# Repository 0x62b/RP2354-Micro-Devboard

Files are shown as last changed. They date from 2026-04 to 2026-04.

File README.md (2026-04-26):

# RP2354-Micro-Devboard
A devboard based on the RP2354 in a small form factor. It is roughly the size of a Seeed Xiao RP2350, and it was going to be pin compatible, before I realised what a messy routing job that was going to be, so I switched the layout for something more logical.

This is probably just going to be used for some small boards that need an RP2350 but that I don't want to directly build the MCU into, without having to go acquire a Xiao, supermini, or something like that.

*many of the files are named as RP2350 because that is what I was using before

The board is compatible with any firmware written for the Pi Pico/RP2350, as long as they don't use the omitted GPIO pins anyway...

Note! The BOM.csv in project root is the LCSC exported BOM with links, while the BOM list in `production/` is the original 
KiCad exported BOM

# Features
* Based on RP2354A with 2MB onboard flash (small flash is a compromise for small size)
* 2 layer PCB (this killed my sanity)
* 10 GPIO outputs
* USB Micro B power/data connection
* a really REALLY messy PCB routing job (it passed DRC tho so I guess thats something...)

Zine page (yes the render is outdated)\
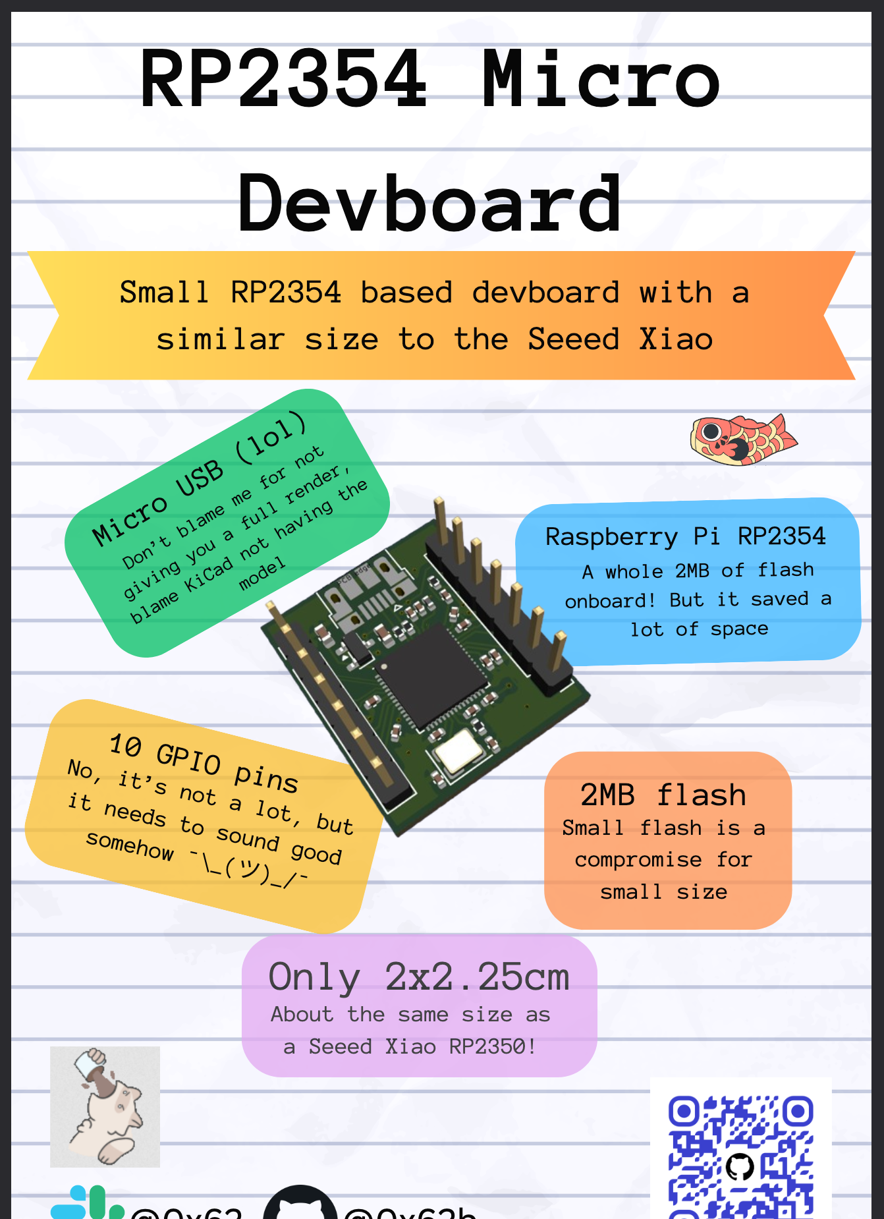
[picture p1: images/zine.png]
zine page


Finished schematic (I'm using the 2350A footprint because they're pin compatible)\
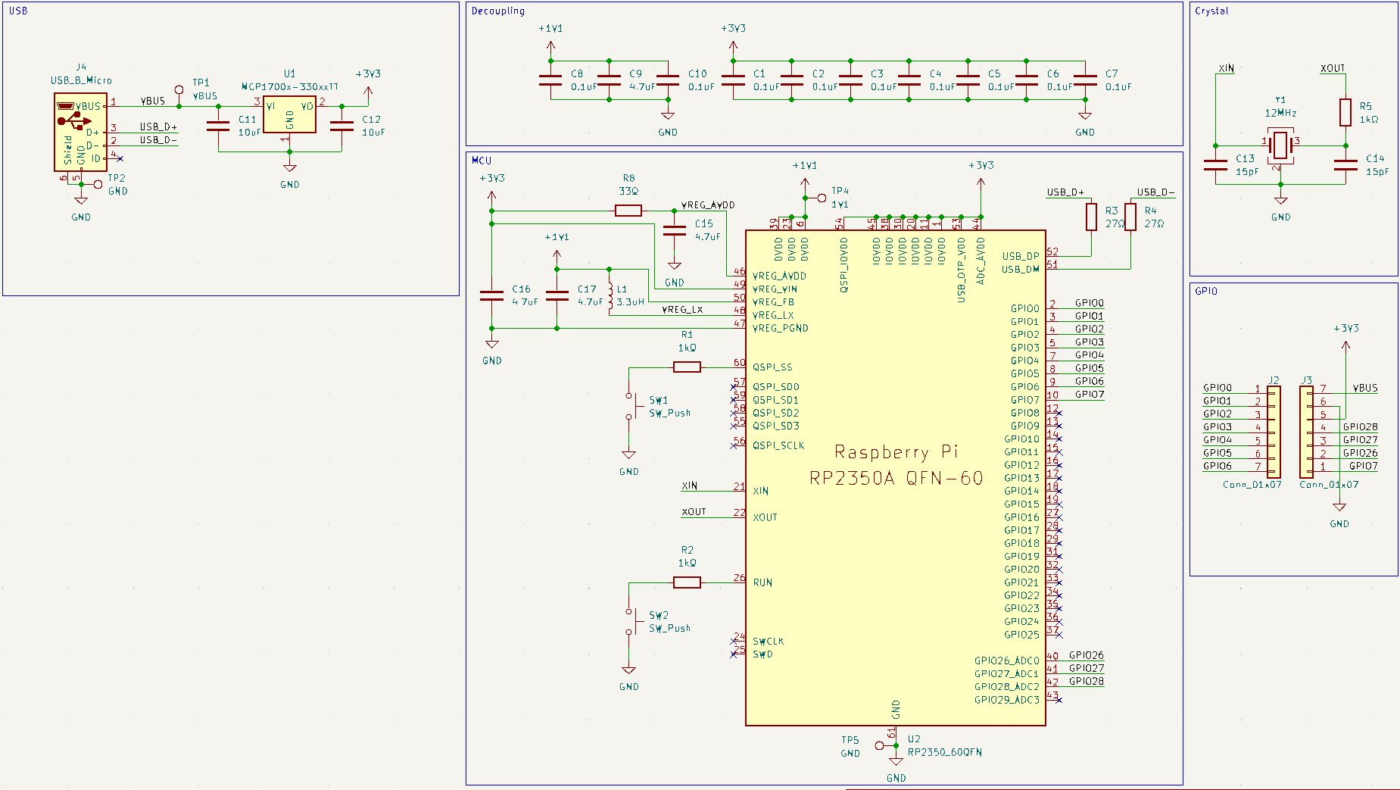
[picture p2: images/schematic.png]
Finished schematic


Finished PCB\
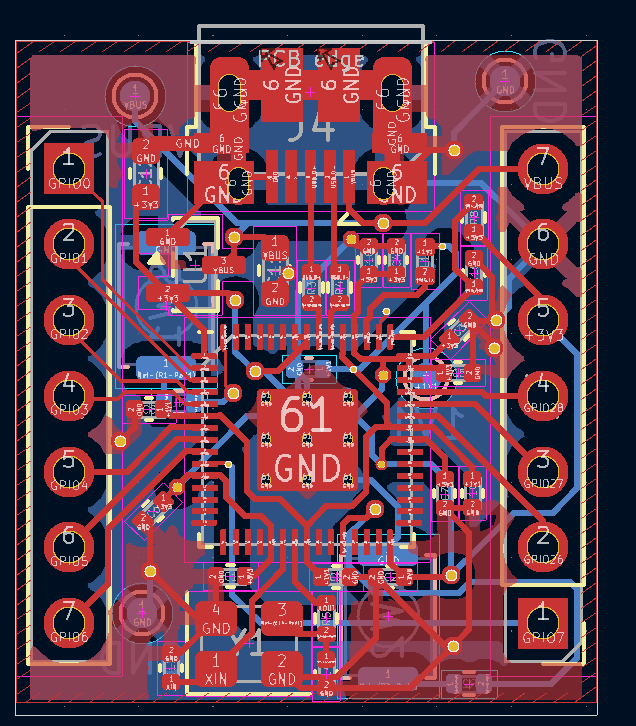
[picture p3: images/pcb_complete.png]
Finished PCB


PCB render\
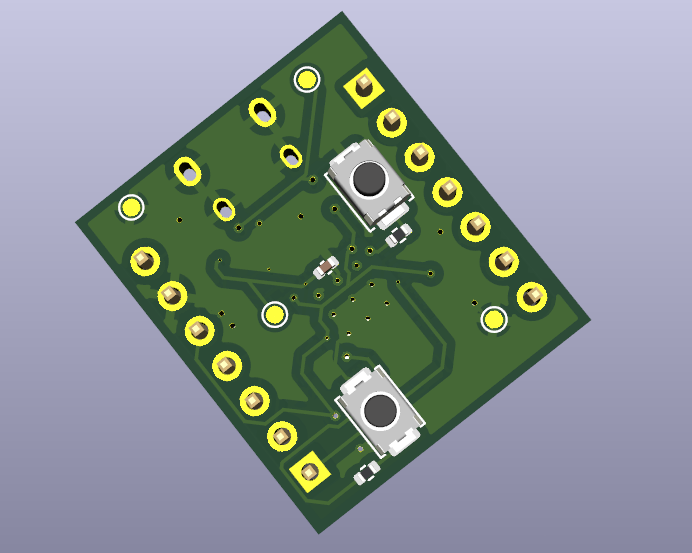
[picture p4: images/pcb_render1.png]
PCB render 1

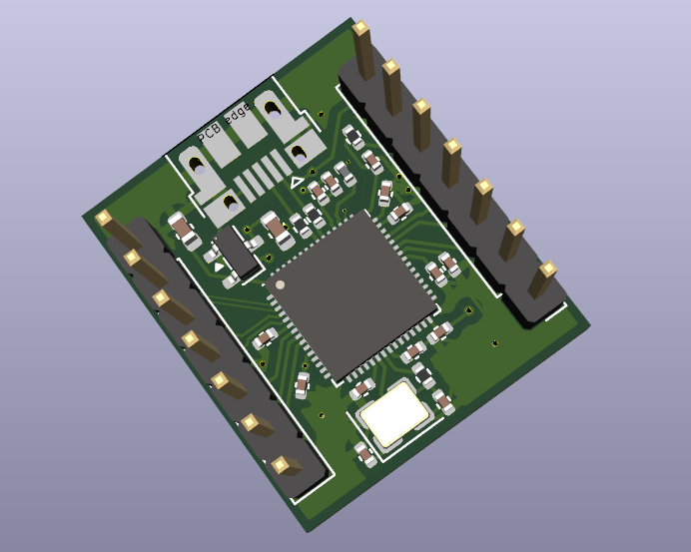
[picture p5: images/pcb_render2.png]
PCB render 2


JLCPCB order\
Extra cost comes from lead-free HASL
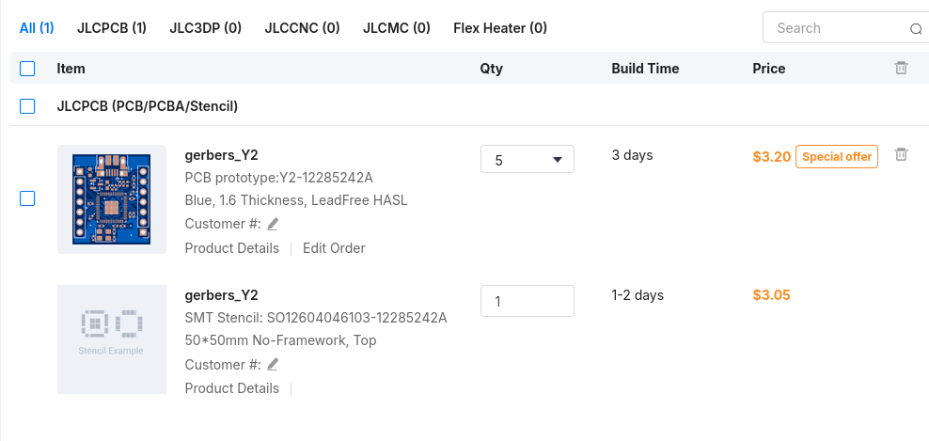
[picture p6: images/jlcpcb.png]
JLCPCB order


LCSC order\
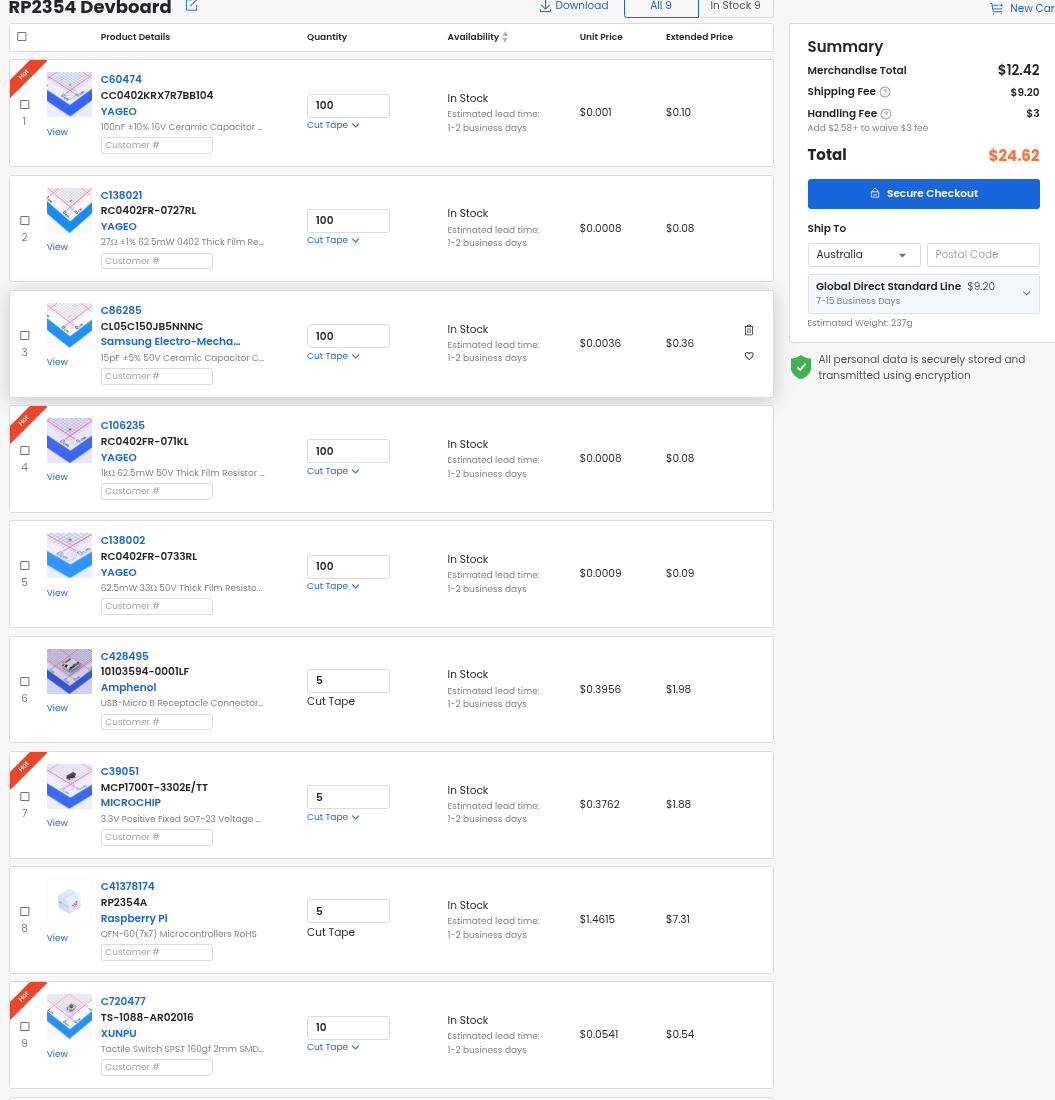
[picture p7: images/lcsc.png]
LCSC order


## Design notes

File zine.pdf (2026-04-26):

## Small RP2354 based devboard with a similar size to the Seeed Xiao

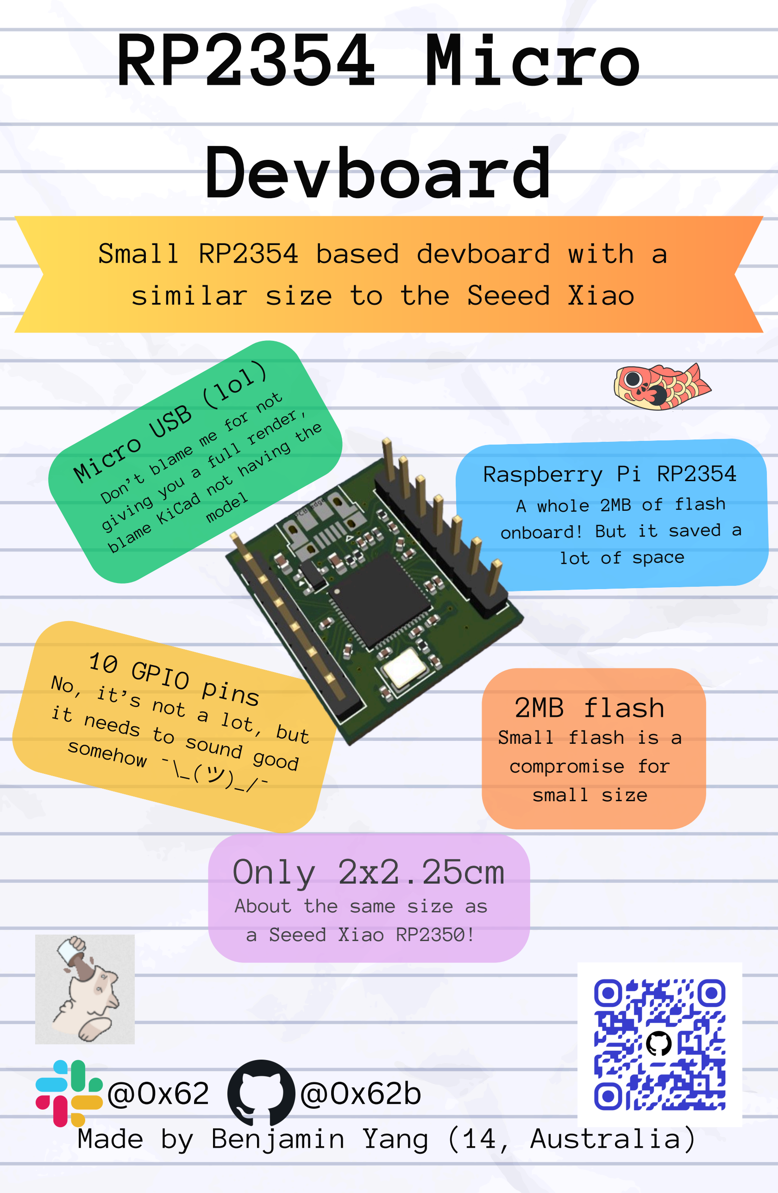
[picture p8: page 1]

# @0x62 @0x62b

## Micro USB (lol)

Don’t blame me for not
giving you a full render,
blame KiCad not having the

model

## 2MB flash

Small flash is a
compromise for
small size

## 10 GPIO pins

### No, it’s not a lot, but it needs to sound good somehow ¯\_(ツ)_/¯

## Raspberry Pi RP2354

A whole 2MB of flash
onboard! But it saved a
lot of space

# Only 2x2.25cm

About the same size as
a Seeed Xiao RP2350!

# RP2354 Micro Devboard

## Made by Benjamin Yang (14, Australia)

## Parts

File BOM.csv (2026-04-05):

RP2350-Micro-Devboard.csv |  |  |  |  |  |  |  |  |  | LCSC BOM Quotation
 |  |  |  |  |  |  |  |  |  | BOM Date Created：05/04/26 15:54:44 |  |  |  | BOM Export Date: 05/04/26 17:32:11 |  |  |  | The matching result is a real-time query result, availability and prices may fluctuate. Backorder items are estimated prices for your reference, please submit "Create Quote" to get the real price. All information is provided "as is" and is subject to change without notice. Any use made of the information provided is without recourse to LCSC and at the user's risk.
 |  |  |  |  |  |  |  |  |  | EST TOTAL :$6.57 |  |  |  | Website：https://www.lcsc.com/bom
Uploaded data |  |  |  |  |  |  |  |  |  | LCSC Matching Results
LCSC# | Mfr. | Mrf# | Description | Package | Value | Customer Part Number | Quantity | Target Price(USD) | Target Lead Time(Business Days) | Mrf# | Mfr. | Order Qty. | Unit Price(USD) | Ext.Price(USD) | LCSC# | Package | Min | Mult | SPQ | Availability | Stock Status | Customer Notes | Description | Matched status | Product Link
 |  |  | 0.1uF | C_0402_1005Metric |  | - | 9 |  |  | CC0402KRX7R7BB104 | YAGEO | 100 | 0.0010 | 0.10 | C60474 | 0402 | 100 | 100 | 10000 | 12680400 | In Stock |  | 100nF ±10% 16V Ceramic Capacitor X7R 0402 | Partial Matches | https://www.lcsc.com/product-detail/C60474.html
 |  |  | 27Ω | R_0402_1005Metric |  | - | 2 |  |  | RC0402FR-0727RL | YAGEO | 100 | 0.0008 | 0.08 | C138021 | 0402 | 100 | 100 | 10000 | 133600 | In Stock |  | 27Ω ±1% 62.5mW 0402 Thick Film Resistor | Partial Matches | https://www.lcsc.com/product-detail/C138021.html
 |  |  | 15pF | C_0402_1005Metric |  | - | 2 |  |  | CL05C150JB5NNNC | Samsung Electro-Mechanics | 100 | 0.0036 | 0.36 | C86285 | 0402 | 100 | 100 | 10000 | 291000 | In Stock |  | 15pF ±5% 50V Ceramic Capacitor C0G 0402 | Partial Matches | https://www.lcsc.com/product-detail/C86285.html
 |  |  | 1kΩ | R_0402_1005Metric |  | - | 3 |  |  | RC0402FR-071KL | YAGEO | 100 | 0.0008 | 0.08 | C106235 | 0402 | 100 | 100 | 10000 | 5019500 | In Stock |  | 1kΩ 62.5mW 50V Thick Film Resistor ±100ppm/℃ ±1% 0402 Chip Resistor - Surface Mount RoHS | Partial Matches | https://www.lcsc.com/product-detail/C106235.html
 |  |  | 33Ω | R_0402_1005Metric |  | - | 1 |  |  | RC0402FR-0733RL | YAGEO | 100 | 0.0009 | 0.09 | C138002 | 0402 | 100 | 100 | 10000 | 258300 | In Stock |  | 62.5mW 33Ω 50V Thick Film Resistor ±100ppm/℃ ±1% 0402 Chip Resistor - Surface Mount RoHS | Partial Matches | https://www.lcsc.com/product-detail/C138002.html
 |  |  | USB_B_Micro | USB_Micro-B_Amphenol_10103594-0001LF_Horizontal_modified |  | - | 1 |  |  | 10103594-0001LF | Amphenol | 5 | 0.3956 | 1.98 | C428495 | SMD | 5 | 5 | 1500 | 26590 | In Stock |  | USB-Micro B Receptacle Connector 5 Position Surface Mount, Right Angle | Partial Matches | https://www.lcsc.com/product-detail/C428495.html
C39051 |  |  | MCP1700x-330xxTT | SOT-23 |  | - | 1 |  |  | MCP1700T-3302E/TT | MICROCHIP | 5 | 0.3762 | 1.88 | C39051 | SOT-23 | 5 | 5 | 3000 | 9525 | In Stock |  | 3.3V Positive Fixed SOT-23 Voltage Regulators - Linear, Low Drop Out (LDO) Regulators RoHS | Exact Matches | https://www.lcsc.com/product-detail/C39051.html
C41378174 |  |  | RP2354_60QFN | RP2354-QFN-60-1EP_7x7_P0.4mm_EP3.4x3.4mm_ThermalVias |  | - | 1 |  |  | RP2354A | Raspberry Pi | 1 | 1.4615 | 1.46 | C41378174 | QFN-60(7x7) | 1 | 1 | 3000 | 156 | In Stock |  | QFN-60(7x7) Microcontrollers RoHS | Exact Matches | https://www.lcsc.com/product-detail/C41378174.html
 |  |  | GND | TestPoint_Pad_D1.0mm |  |  | 2 |  |  | -(The data has been deleted.) | - | - | - | - | - | - | - | - | - | - | - | - | - | -
 |  |  | 1V1 | TestPoint_Pad_D1.0mm |  |  | 1 |  |  | -(The data has been deleted.) | - | - | - | - | - | - | - | - | - | - | - | - | - | -
C720477 |  |  | SW_Push | SW_Push_SPST_NO_Alps_SKRK |  | - | 2 |  |  | TS-1088-AR02016 | XUNPU | 10 | 0.0541 | 0.54 | C720477 | SMD,4x3mm | 10 | 10 | 4000 | 390540 | In Stock |  | Tactile Switch SPST 160gf 2mm SMD (SMT) Tab 4mm x 3mm Surface Mount | Exact Matches | https://www.lcsc.com/product-detail/C720477.html
 |  |  | VBUS | TestPoint_Pad_D1.0mm |  |  | 1 |  |  | -(The data has been deleted.) | - | - | - | - | - | - | - | - | - | - | - | - | - | -

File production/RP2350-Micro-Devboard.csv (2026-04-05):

Id | Designator | Footprint | Quantity | Designation | Supplier and ref
1 | C16,C15,C9,C17 | C_0402_1005Metric | 4 | 4.7uF
2 | J3,J2 | PinHeader_1x07_P2.54mm_Vertical | 2 | Conn_01x07
3 | Y1 | Crystal_SMD_3225-4Pin_3.2x2.5mm | 1 | 12MHz
4 | C12,C11 | C_0603_1608Metric | 2 | 10uF
5 | L1 | L_0402_1005Metric | 1 | 3.3uH
6 | C7,C10,C4,C5,C8,C6,C2,C3,C1 | C_0402_1005Metric | 9 | 0.1uF
7 | R3,R4 | R_0402_1005Metric | 2 | 27Ω
8 | C13,C14 | C_0402_1005Metric | 2 | 15pF
9 | R5,R1,R2 | R_0402_1005Metric | 3 | 1kΩ
10 | R8 | R_0402_1005Metric | 1 | 33Ω
11 | J4 | USB_Micro-B_Amphenol_10103594-0001LF_Horizontal_modified | 1 | USB_B_Micro
12 | U1 | SOT-23 | 1 | MCP1700x-330xxTT
13 | U2 | RP2350-QFN-60-1EP_7x7_P0.4mm_EP3.4x3.4mm_ThermalVias | 1 | RP2350_60QFN
14 | TP2,TP5 | TestPoint_Pad_D1.0mm | 2 | GND
15 | TP4 | TestPoint_Pad_D1.0mm | 1 | 1V1
16 | SW1,SW2 | SW_Push_SPST_NO_Alps_SKRK | 2 | SW_Push
17 | TP1 | TestPoint_Pad_D1.0mm | 1 | VBUS

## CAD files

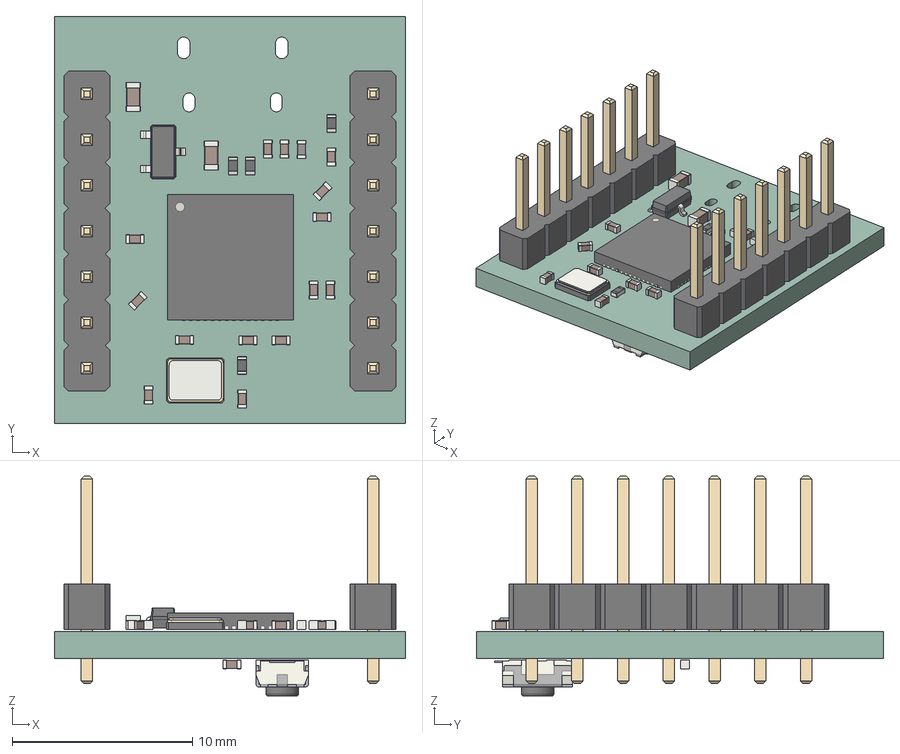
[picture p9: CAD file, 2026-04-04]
cad/RP2350-Micro-Devboard.step
19.5 x 22.6 x 12.2 mm
C_0402_1005Metric x 15
PinHeader_1x07_P2.54mm_Vertical x 2
Crystal_SMD_3225-4Pin_3.2x2.5mm
C_0603_1608Metric x 2
L_0402_1005Metric
R_0402_1005Metric x 4
SOT-23
QFN-56-1EP_7x7mm_P0.4mm_EP5.6x5.6mm
SW_Push_SPST_NO_Alps_SKRK
RP2350-Micro-Devboard_PCB

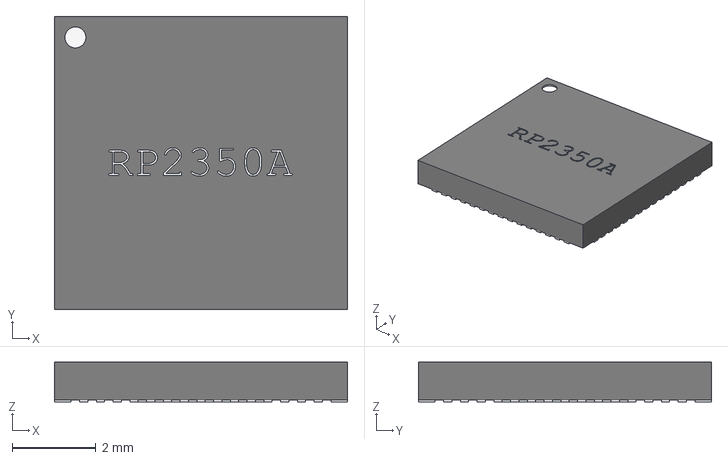
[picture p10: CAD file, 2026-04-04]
pcb/RP2350_QFN60.step
7.00 x 7.00 x 0.95 mm

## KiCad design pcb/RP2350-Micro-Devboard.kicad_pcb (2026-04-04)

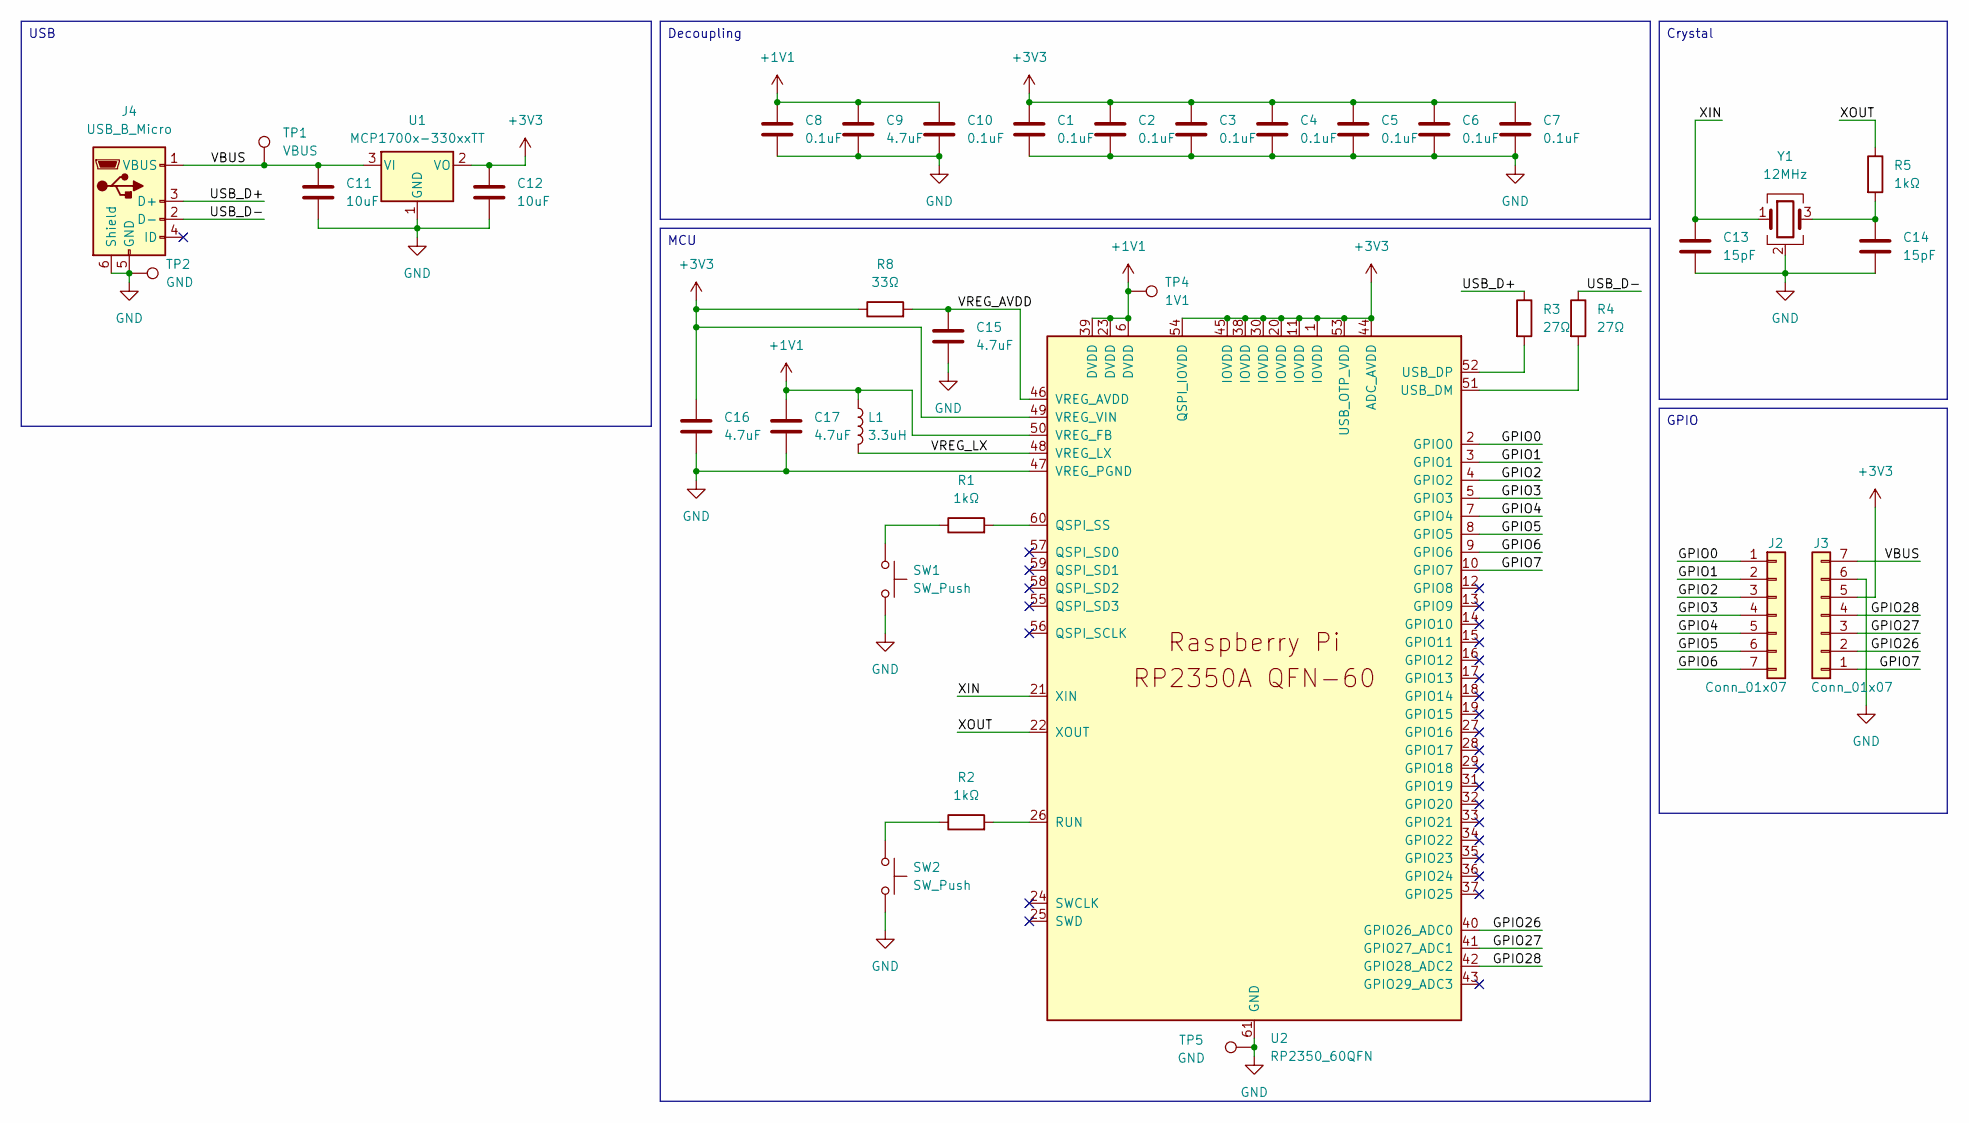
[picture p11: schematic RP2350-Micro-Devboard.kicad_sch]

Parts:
C1, C2, C3, C4, C5, C6, C7, C8, C10: 0.1uF; C_0402_1005Metric
C9, C15, C16, C17: 4.7uF; C_0402_1005Metric
C11, C12: 10uF; C_0603_1608Metric
C13, C14: 15pF; C_0402_1005Metric
J2, J3: Conn_01x07; PinHeader_1x07_P2.54mm_Vertical
J4: USB_B_Micro; USB_Micro-B_Amphenol_10103594-0001LF_Horizontal_modified
L1: 3.3uH; L_0402_1005Metric
R1, R2, R5: 1kΩ; R_0402_1005Metric
R3, R4: 27Ω; R_0402_1005Metric
R8: 33Ω; R_0402_1005Metric
SW1, SW2: SW_Push; SW_Push_SPST_NO_Alps_SKRK
TP1: VBUS; TestPoint_Pad_D1.0mm
TP2, TP5: GND; TestPoint_Pad_D1.0mm
TP4: 1V1; TestPoint_Pad_D1.0mm
U1: MCP1700x-330xxTT; SOT-23
U2: RP2350_60QFN; RP2350-QFN-60-1EP_7x7_P0.4mm_EP3.4x3.4mm_ThermalVias
Y1: 12MHz; Crystal_SMD_3225-4Pin_3.2x2.5mm

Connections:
+1V1: C8.1, C9.1, C10.1, C17.1, L1.1, TP4.1, U2.6 (DVDD), U2.23 (DVDD), U2.39 (DVDD), U2.50 (VREG_FB)
+3V3: C1.1, C2.1, C3.1, C4.1, C5.1, C6.1, C7.1, C12.1, C16.1, J3.5, R8.1, U1.2 (VO), U2.1 (IOVDD), U2.11 (IOVDD), U2.20 (IOVDD), U2.30 (IOVDD), U2.38 (IOVDD), U2.44 (ADC_AVDD), U2.45 (IOVDD), U2.49 (VREG_VIN), U2.53 (USB_OTP_VDD), U2.54 (QSPI_IOVDD)
/GPIO0: J2.1, U2.2 (GPIO0)
/GPIO1: J2.2, U2.3 (GPIO1)
/GPIO2: J2.3, U2.4 (GPIO2)
/GPIO3: J2.4, U2.5 (GPIO3)
/GPIO4: J2.5, U2.7 (GPIO4)
/GPIO5: J2.6, U2.8 (GPIO5)
/GPIO6: J2.7, U2.9 (GPIO6)
/GPIO7: J3.1, U2.10 (GPIO7)
/GPIO26: J3.2, U2.40 (GPIO26_ADC0)
/GPIO27: J3.3, U2.41 (GPIO27_ADC1)
/GPIO28: J3.4, U2.42 (GPIO28_ADC2)
/USB_D+: J4.3 (D+), R3.1
/USB_D-: J4.2 (D-), R4.1
/VBUS: C11.1, J3.7, J4.1 (VBUS), TP1.1, U1.3 (VI)
/VREG_AVDD: C15.1, R8.2, U2.46 (VREG_AVDD)
/VREG_LX: L1.2, U2.48 (VREG_LX)
/XIN: C13.1, U2.21 (XIN), Y1.1
/XOUT: R5.1, U2.22 (XOUT)
GND: C1.2, C2.2, C3.2, C4.2, C5.2, C6.2, C7.2, C8.2, C9.2, C10.2, C11.2, C12.2, C13.2, C14.2, C15.2, C16.2, C17.2, J3.6, J4.5 (GND), J4.6 (Shield), SW1.2, SW2.2, TP2.1, TP5.1, U1.1 (GND), U2.47 (VREG_PGND), U2.61 (GND), Y1.2 (G), Y1.4 (G)
unnamed: C14.1, R5.2, Y1.3
unnamed: R1.1, SW1.1
unnamed: R2.1, SW2.1
unnamed: R1.2, U2.60 (QSPI_SS)
unnamed: R2.2, U2.26 (RUN)
unnamed: R4.2, U2.51 (USB_DM)
unnamed: R3.2, U2.52 (USB_DP)

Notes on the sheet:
GPIO
Crystal
MCU
USB
Decoupling

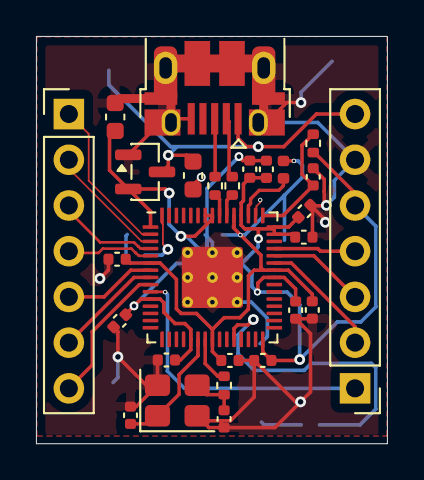
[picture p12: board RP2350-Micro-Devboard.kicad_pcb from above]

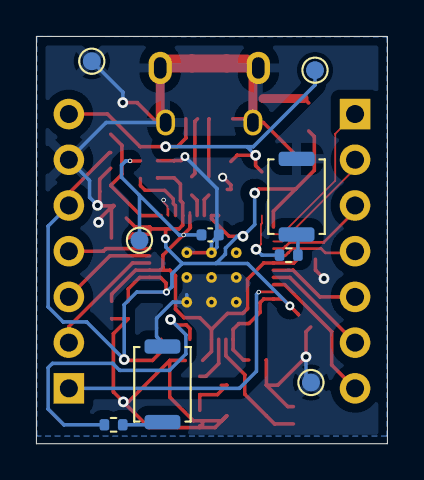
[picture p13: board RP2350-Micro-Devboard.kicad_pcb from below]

Board: 2 copper layers, 19.5 x 22.6 mm, 36 parts (9 on the bottom side), 28 nets.

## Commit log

2026-04-04 first completion of shitty routing
    [RP2350-Micro-Devboard.kicad_pcb, RP2350-Micro-Devboard.kicad_sch]
2026-04-04 fix the drc
    [RP2350-Micro-Devboard.kicad_pcb]
2026-04-04 add production files
    [RP2350-Micro-Devboard-B_Cu.gbr, RP2350-Micro-Devboard-B_Mask.gbr, RP2350-Micro-Devboard-B_Paste.gbr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]
2026-04-04 add 3d model
    [RP2350-Micro-Devboard.step]
2026-04-04 symbol/footprint libraries
    [RP2350-Micro-Devboard.kicad_pcb]
2026-04-04 more files
    i have no idea if you need this or if this even works
    [RP2350_QFN60.step]
2026-04-04 more prod files
    [RP2350-Micro-Devboard.csv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]
2026-04-04 fix and make consistent values
    [RP2350-Micro-Devboard.kicad_sch]
2026-04-04 add testpoints, add buttons
    [RP2350-Micro-Devboard.kicad_pcb, RP2350-Micro-Devboard.kicad_sch]
2026-04-04 new production files
    [RP2350-Micro-Devboard-B_Cu.gbr, RP2350-Micro-Devboard-B_Mask.gbr, RP2350-Micro-Devboard-B_Paste.gbr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]
2026-04-04 new schematic + pcb screenshots
2026-04-05 updated bom
    [RP2350-Micro-Devboard.csv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]
2026-04-05 repo organisation
    [BOM.csv, RP2350-Micro-Devboard.kicad_pcb, RP2350-Micro-Devboard.kicad_sch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]
2026-04-05 bom note
